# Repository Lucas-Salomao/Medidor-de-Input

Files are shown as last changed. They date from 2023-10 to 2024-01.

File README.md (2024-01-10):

# Dispositivo portátil de medição de input

Este dispositivo é capaz de medir o tempo entre 2 pulsos de um sensor e converter esse tempo em uma tensão de 0-5V, dividido em 2 canais, um para segundos inteiros e outro para milisegundos.

## Características

- Tensão de alimentação: 10-30 VDC
- Display LCD de 2 linhas e 16 colunas para exibição
- Memória EEPROM para armazenar configuração e dados de calibração.
- 1 porta de comunicação serial-USB
- Encoder rotativo para parametrização
- Acurácia de ± 1LSB
- 12 bits de resolução

## Diagrama Esquemático



## Pinout Arduino Nano



## Procedimentos para Compilação e Gravação

O projeto foi desenvolvido no Visual Studio Code, utilizando a extensão [PlatformIO](https://platformio.org/).

É necessário ter o [Arduino IDE Legacy](https://www.arduino.cc/en/software) instalado para poder compilar e gravar a aplicação.

Fazer o download deste repositório, descompactar a pasta e abrir a pasta pelo Visual Studio Code. Assim toda a estrutura do projeto será reconhecida.

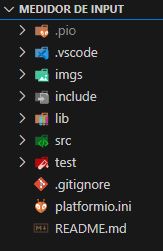
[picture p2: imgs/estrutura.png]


Para compilar o projeto basta utilizar o seguinte atalho no teclado: CTRL+ALT+B. É possível também utilizar o atalho clicando no ícone que se encontra no rodapé do Visual Studio Code.



Para fazer o upload do programa para o dispositivo, com o cabo USB inserido no dispositivo e no computador, utilize o seguinte atalho no teclado: CTRL+ALT+U. É possível também utilizar o atalho clicando no ícone que se encontra no rodapé do Visual Studio Code.



Todas as bibliotecas utilizadas são listadas no arquivo [platfomio.ini](/platformio.ini) e são instaladas assim que a estrutura do projeto é aberto no Visual Studio Code. Para utilizar o Arduino IDE será necessário instalar manualmente cada biblioteca.

## Modo de Funcionamento

Ao energizar o equipamento está pronto para operação, apresentando a seguinte tela:

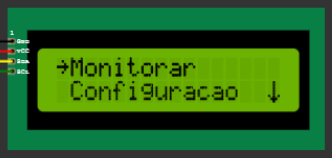
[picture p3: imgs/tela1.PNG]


Nesta tela temos as 2 opções disponíveis, Monitoramento e Configuração.

O encoder rotativo é utilizado para a navegação no menu.

Rotacionando no sentido horário, os valores são incrementados e o menu é deslocado para baixo.

Rotacionando no sentido anti-horário, os valores são decrementados e o menu é deslocado para cima.

O encoder rotativo também apresenta um botão. Quando pressionado o centro do encoder, esse botão é acionado. O Botão apresenta 3 funções:

- Pressionando 1 vez o comando ENTER é enviado.
- Prssionando 2 vezes o comando VOLTAR é enviado e o menu volta um nível acima.
- Pressionando 3 vezes o comando RESET é enviado e o dispositivo é reiniciado.
- Pressionando 1 vez e segurando pelo menos 500ms, o comando APAGAR é enviado e o valor atual selecionado no display é apagado.

No menu Monitoramento podemos encontrar os valores de tempo medidos e os respectivos valores de tensão na saída, calculados.

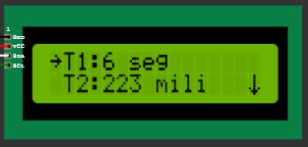
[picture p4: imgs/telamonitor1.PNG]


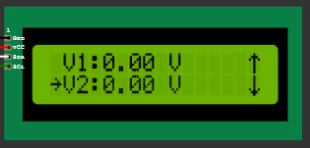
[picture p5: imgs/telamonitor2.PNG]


No menu Configuração podemos configurar os seguintes parâmetros:

- Quantidades de Voltas
- Tempo Máximo de Amostragem
- Precisão da Saída Analógica
- Habilitar Rotina de Teste
- Tempo da Rotina de Teste
- Apagar Memória EEPROM

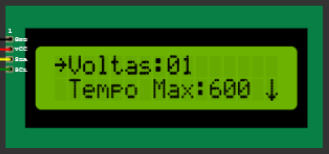
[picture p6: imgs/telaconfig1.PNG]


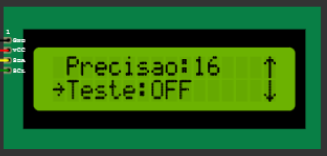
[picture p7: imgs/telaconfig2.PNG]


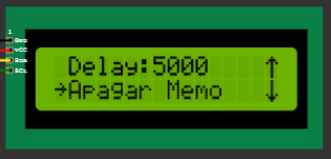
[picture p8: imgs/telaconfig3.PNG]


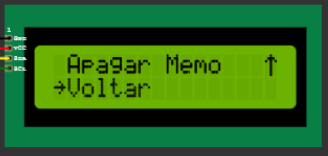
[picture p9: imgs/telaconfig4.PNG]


Para configurar algum valor de parâmetro, basta selecionar o parâmetro desejado e pressionar 1 vez o botão do encoder. O cursor piscará esperando o novo valor. Com o encoder, gire até o valor desejado. Para confirmar o valor, pressione 1 vez novamente o encoder. Caso necessite de mais um algarismo, escolha através do giro do encoder e confirme novamente pressionando 1 vez o encoder. Caso necessite apagar algum algarismo, pressione e segure por pelo menos 500ms o encoder e espere o algarismo ser apagado no display. Caso tenha terminado a configuração, pressione 2 vezes o botão do encoder para voltar ao menu de configuração.

## Licença

[MIT](https://choosealicense.com/licenses/mit/)

## Suporte

Para suporte, mande um e-mail para contato@dksolutions.com.br.

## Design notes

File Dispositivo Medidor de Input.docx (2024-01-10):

DESCRITIVO TÉCNICO

DISPOSITIVO PORTÁTIL DE

MEDIÇÃO DE INPUT

# Dispositivo portátil de medição de input

Este dispositivo é capaz de medir o tempo entre 2 pulsos de um sensor e converter esse tempo em uma tensão de 0-5V, dividido em 2 canais, um para segundos inteiros e outro para milisegundos.

## Características

- Tensão de alimentação: 10-30 VDC
- Display LCD de 2 linhas e 16 colunas para exibição
- Memória EEPROM para armazenar configuração e dados de calibração.
- 1 porta de comunicação serial-USB
- Encoder rotativo para parametrização
- Acurácia de ± 1LSB
- 12 bits de resolução

## Diagrama Esquemático

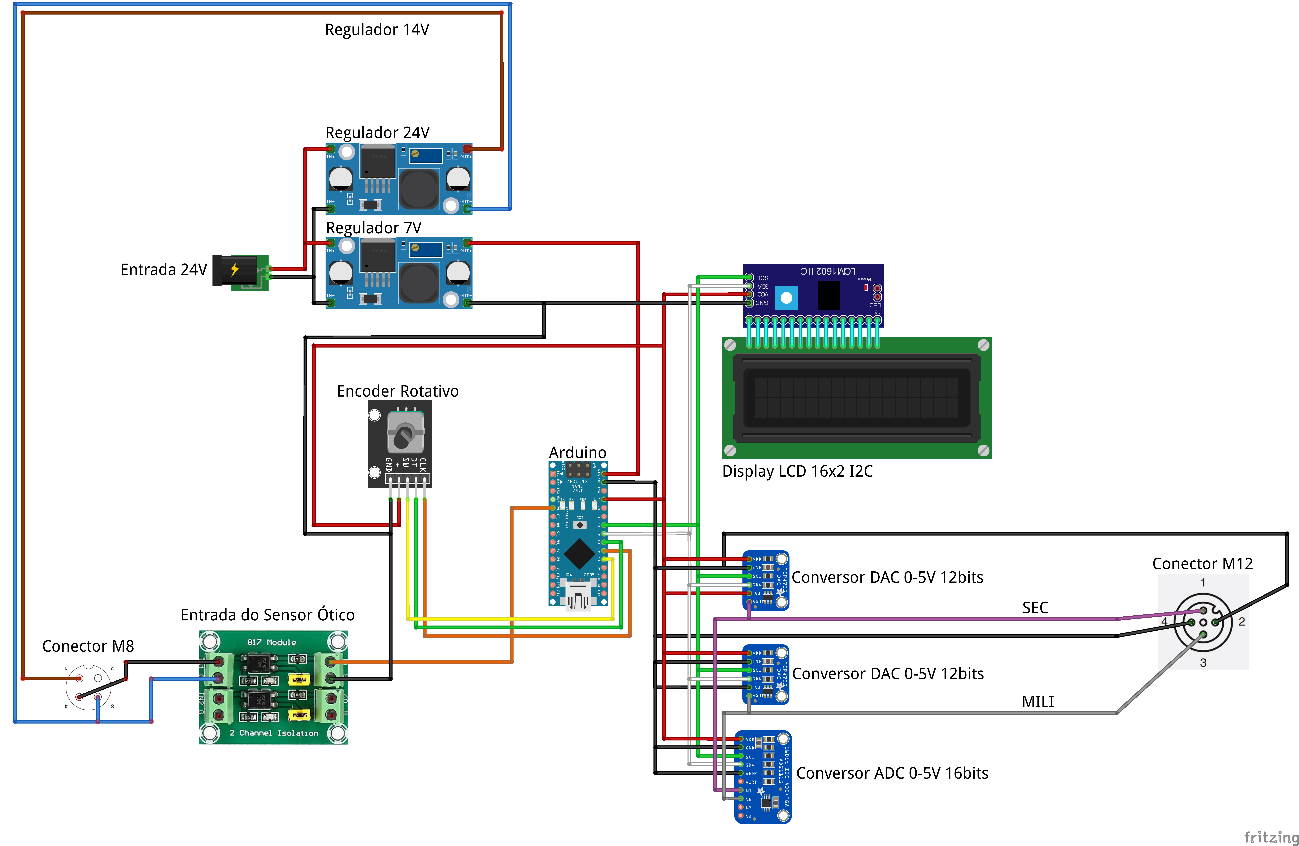
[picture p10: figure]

## Pinout Arduino Nano

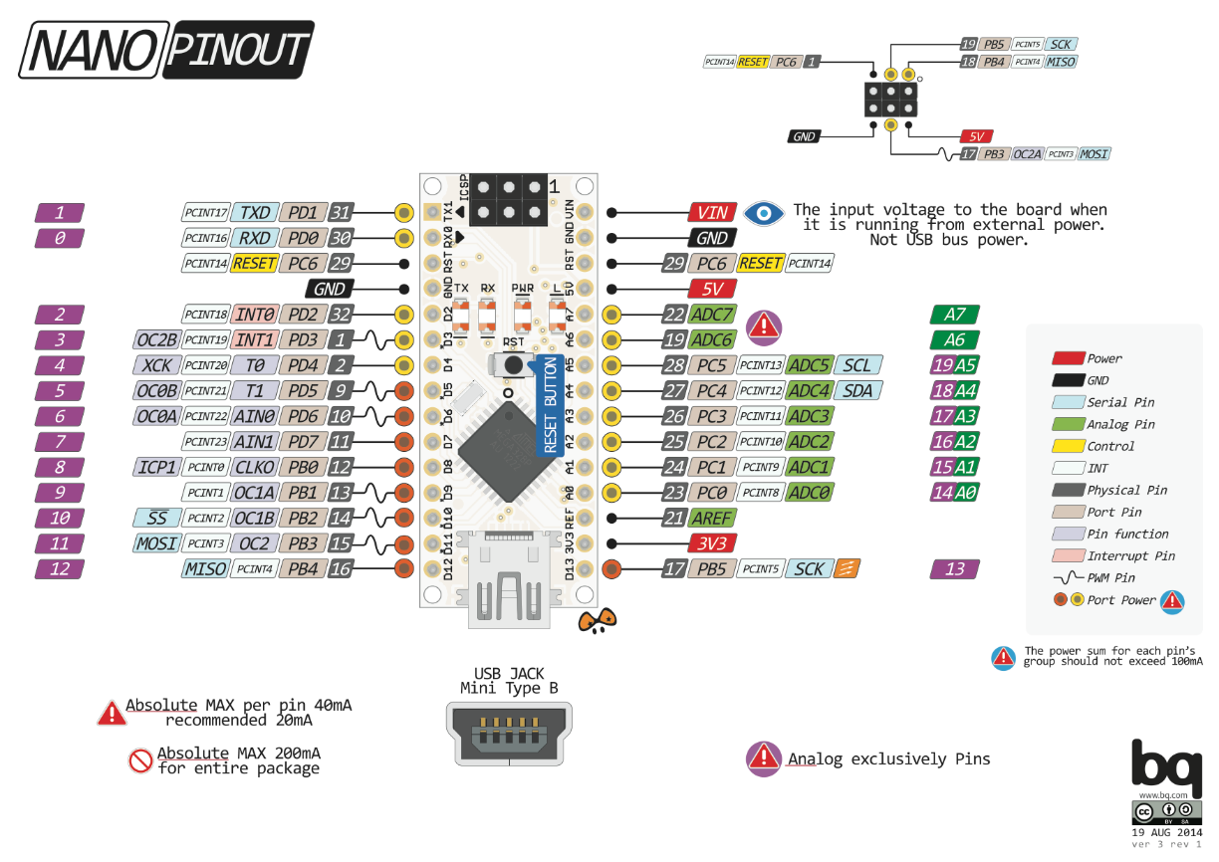
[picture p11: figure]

## Procedimentos para Compilação e Gravação

O projeto foi desenvolvido no Visual Studio Code, utilizando a extensão PlatformIO (https://platformio.org/).

É necessário ter o Arduino IDE Legacy (https://www.arduino.cc/en/software) instalado para poder compilar e gravar a aplicação.

Fazer o download deste repositório, descompactar a pasta e abrir a pasta pelo Visual Studio Code. Assim toda a estrutura do projeto será reconhecida.


Para compilar o projeto basta utilizar o seguinte atalho no teclado: CTRL+ALT+B. É possível também utilizar o atalho clicando no ícone que se encontra no rodapé do Visual Studio Code.

Para fazer o upload do programa para o dispositivo, com o cabo USB inserido no dispositivo e no computador, utilize o seguinte atalho no teclado: CTRL+ALT+U. É possível também utilizar o atalho clicando no ícone que se encontra no rodapé do Visual Studio Code.

Todas as bibliotecas utilizadas são listadas no arquivo platfomio.ini (https://github.com/Lucas-Salomao/Medidor-de-Input/blob/novo-update-display/platformio.ini) e são instaladas assim que a estrutura do projeto é aberto no Visual Studio Code. Para utilizar o Arduino IDE será necessário instalar manualmente cada biblioteca.

## Modo de Funcionamento

Ao energizar o equipamento está pronto para operação, apresentando a seguinte tela:


Nesta tela temos as 2 opções disponíveis, Monitoramento e Configuração.

O encoder rotativo é utilizado para a navegação no menu.

Rotacionando no sentido horário, os valores são incrementados e o menu é deslocado para baixo.

Rotacionando no sentido anti-horário, os valores são decrementados e o menu é deslocado para cima.

O encoder rotativo também apresenta um botão. Quando pressionado o centro do encoder, esse botão é acionado. O Botão apresenta 3 funções:

- Pressionando 1 vez o comando ENTER é enviado.
- Pressionando 2 vezes o comando VOLTAR é enviado e o menu volta um nível acima.
- Pressionando 3 vezes o comando RESET é enviado e o dispositivo é reiniciado.
- Pressionando 1 vez e segurando pelo menos 500ms, o comando APAGAR é enviado e o valor atual selecionado no display é apagado.

No menu Monitoramento podemos encontrar os valores de tempo medidos e os respectivos valores de tensão na saída, calculados.


No menu Configuração podemos configurar os seguintes parâmetros:

- Quantidades de Voltas
- Tempo Máximo de Amostragem
- Precisão da Saída Analógica
- Habilitar Rotina de Teste
- Tempo da Rotina de Teste
- Apagar Memória EEPROM


Para configurar algum valor de parâmetro, basta selecionar o parâmetro desejado e pressionar 1 vez o botão do encoder. O cursor piscará esperando o novo valor. Com o encoder, gire até o valor desejado. Para confirmar o valor, pressione 1 vez novamente o encoder. Caso necessite de mais um algarismo, escolha através do giro do encoder e confirme novamente pressionando 1 vez o encoder. Caso necessite apagar algum algarismo, pressione e segure por pelo menos 500ms o encoder e espere o algarismo ser apagado no display. Caso tenha terminado a configuração, pressione 2 vezes o botão do encoder para voltar ao menu de configuração.

## Licença

MIT (https://choosealicense.com/licenses/mit/)

## Suporte

Para suporte, mande um e-mail para contato@dksolutions.com.br

contato@dksolutions.com.br | 11 2640-3475 / 9.3440-5066 | www.dksolutions.com.br

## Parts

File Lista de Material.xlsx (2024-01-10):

Descrição | Quantidade | Valor | Fornecedor 1 | Fornecedor 2 | Fornecedor 3 | Fornecedor 4 | Fornecedor 5
Arduino Nano | 1 | R$61.65 | https://www.makerhero.com/produto/placa-nano-v3-0-cabo-usb-para-arduino/ |  |  | https://www.autocorerobotica.com.br/arduino-nano-v3-0-compativel-com-cabo-usb | https://www.baudaeletronica.com.br/produto/arduino-nano-r3-compativel-cabo-mini-usb.html
Base com borne Arduino Nano | 1 | R$15.10 | https://www.makerhero.com/produto/nano-shield-para-arduino/ | https://www.eletrogate.com/placa-de-expansao-para-arduino-nano-desmontada |  | https://www.autocorerobotica.com.br/nano-shield-placa-de-expansao-arduino | https://www.baudaeletronica.com.br/produto/shield-de-expansao-com-borne-para-arduino-nano-diy.html
Regulador de Tensão LM2596 | 2 | R$9.40 | https://www.makerhero.com/produto/regulador-de-tensao-lm2596-conversor-dc-dc-step-down/ |  |  | https://www.autocorerobotica.com.br/modulo-regulador-de-tensao-ajustavel-lm2596 | Módulo Regulador de Tensão LM2596 | Baú da Eletrônica - Baú da Eletrônica - Componentes Eletrônicos (baudaeletronica.com.br) (https://www.baudaeletronica.com.br/produto/modulo-regulador-de-tensao-lm2596.html)
Encoder KY-040 | 1 | R$9.40 | https://www.makerhero.com/produto/encoder-decoder-ky-040-rotacional/ | https://www.eletrogate.com/encoder-decoder-ky-040-rotacional |  | https://www.autocorerobotica.com.br/modulo-encoder-rotacional-com-knob | Encoder Decoder KY-040 Rotacional | Baú da Eletrônica - Baú da Eletrônica - Componentes Eletrônicos (baudaeletronica.com.br) (https://www.baudaeletronica.com.br/produto/encoder-decoder-ky-040-rotacional.html)
Display LCD 16x2 com I2C | 1 | R$36.00 | https://www.makerhero.com/produto/display-lcd-16x2-i2c-backlight-azul/ | https://www.eletrogate.com/display-lcd-16x2-i2c-backlight-azul |  | Display Lcd 16x2 com Adaptador I2C Backlight Azul - AutoCore Robótica (autocorerobotica.com.br) (https://www.autocorerobotica.com.br/display-lcd-16x2-com-adaptador-i2c-backlight-azul) | https://www.baudaeletronica.com.br/produto/display-lcd-16x2-azul-com-modulo-adaptador-i2c.html
Optoacoplador | 1 | R$16.90 |  | Módulo Optoacoplador 2 Canais - PC817 - Eletrogate | Arduino, Robótica, IoT, Apostilas e Kits (https://www.eletrogate.com/modulo-optoacoplador-2-canais-pc817) |  |  | Módulo Optoacoplador PC817 com 2 Canais | Baú da Eletrônica - Baú da Eletrônica - Componentes Eletrônicos (baudaeletronica.com.br) (https://www.baudaeletronica.com.br/produto/modulo-optoacoplador-pc817-com-2-canais.html)
Conector P4 | 1 | R$2.38 |  | Conector Jack P4 Femea (J4 2,1mm) DC-022 - Eletrogate | Arduino, Robótica, IoT, Apostilas e Kits (https://www.eletrogate.com/conector-jack-p4-femea-j4-21mm-dc-022)
Conversor Digital Analógico MCP4725 12bits | 2 | R$28.40 | Conversor Digital Analógico DAC MCP4725 I2C - MakerHero (https://www.makerhero.com/produto/conversor-digital-analogico-dac-mcp4725-i2c/) | Conversor Digital Analógico MCP4725 - Eletrogate | Arduino, Robótica, IoT, Apostilas e Kits (https://www.eletrogate.com/conversor-digital-analogico-mcp4725) |  | Módulo MCP4725 Conversor Digital Analógico - AutoCore Robótica (autocorerobotica.com.br) (https://www.autocorerobotica.com.br/modulo-mcp4725-conversor-digital-analogico) | Conversor Digital Analógico DAC - MCP4725 I2C | Baú da Eletrônica - Baú da Eletrônica - Componentes Eletrônicos (baudaeletronica.com.br) (https://www.baudaeletronica.com.br/produto/conversor-digital-analogico-dac-mcp4725-i2c.html)
Conversor Analógico Digital ADS1115 | 1 |  | https://www.makerhero.com/produto/conversor-analogico-digital-4-canais-ads1115/ | https://www.eletrogate.com/modulo-conversor-analogico-digital-adc-ads1115 |  | https://www.autocorerobotica.com.br/modulo-adc-ads1115 | https://www.baudaeletronica.com.br/produto/conversor-analogicodigital-i2c-16-bits-ads1115.html
Caixa Patola PB-119/2 | 1 | R$43.90 |  |  |  |  | Caixa Plástica Patola PB-119/2 | Baú da Eletrônica - Baú da Eletrônica - Componentes Eletrônicos (baudaeletronica.com.br) (https://www.baudaeletronica.com.br/produto/caixa-plastica-patola-pb-1192.html)
Kit de Espaçadores | 1 | R$82.98 |  |  |  |  | https://www.baudaeletronica.com.br/produto/kit-espacadores-m3.html
Cabo Manga 8 vias sem blindagem | 2 | R$8.55 |  |  |  |  | https://www.baudaeletronica.com.br/produto/cabo-manga-8x26-8-vias-26-awg-014mm2-sem-blindagem.html
Conector M12 Fêmea Painel | 1 | R$43.00 |  |  | https://www.recontrolstore.com.br/cabos-e-acessorios/conector-m12-painel-4-pinos-femea-
Conector M12 Macho Reto | 1 | R$34.00 |  |  | https://www.recontrolstore.com.br/conectores-montaveis-m12-m8/conector-m12-pg7-reto-4pin-macho
Conector M8 Fêmea Painel | 1 | R$45.00 |  |  | CONECTOR M8 PAINEL 4 PINOS FEMEA - R.E. Control Store (recontrolstore.com.br) (https://www.recontrolstore.com.br/conectores-montaveis/conectores-m8/conector-m8-painel-4-pinos-femea)
TOTAL |  | R$436.66

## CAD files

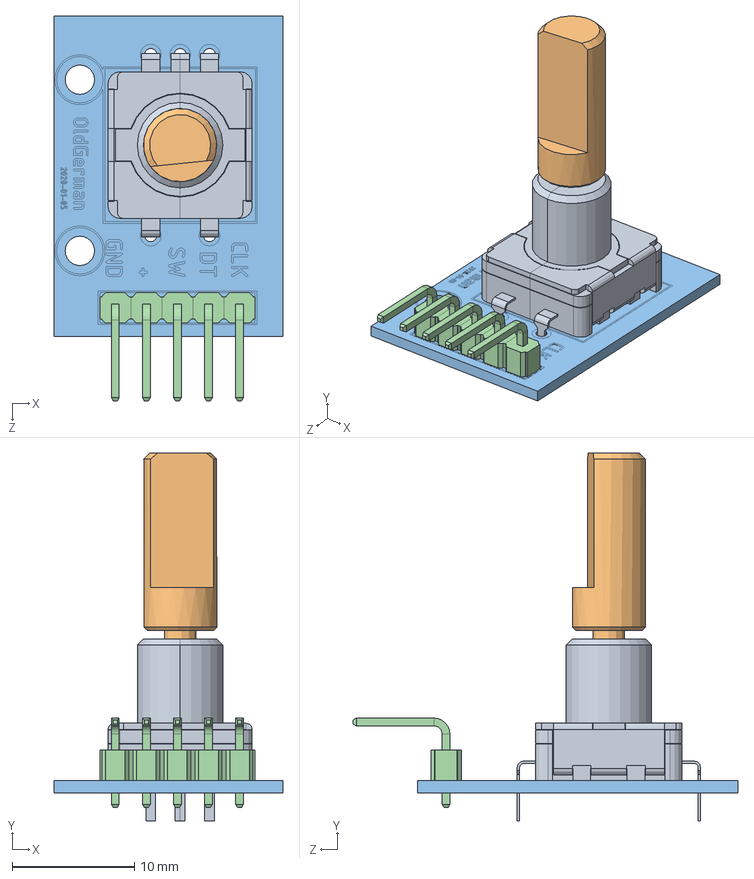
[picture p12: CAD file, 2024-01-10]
3D/KY-040 Rotary Encoder.SLDASM
18.7 x 30.1 x 31.5 mm
Rotary Encoder
D-handle
pcb
2.54 5PIN 90

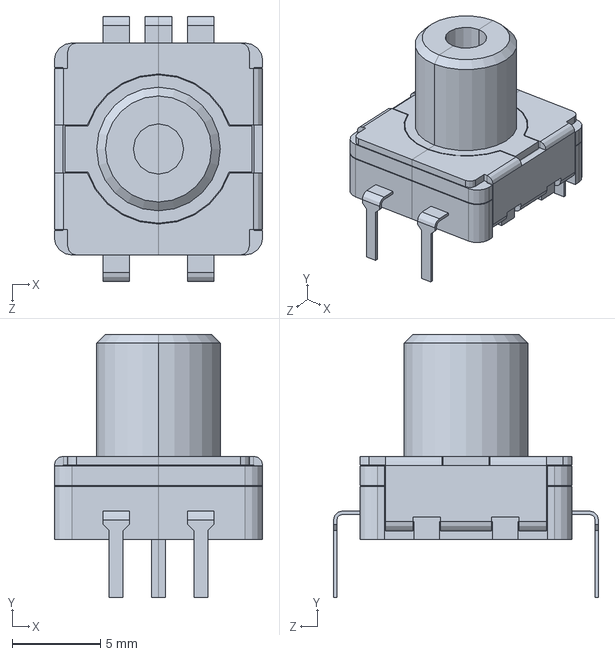
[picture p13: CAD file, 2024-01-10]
3D/Rotary Encoder.SLDPRT
11.8 x 14.9 x 15.0 mm

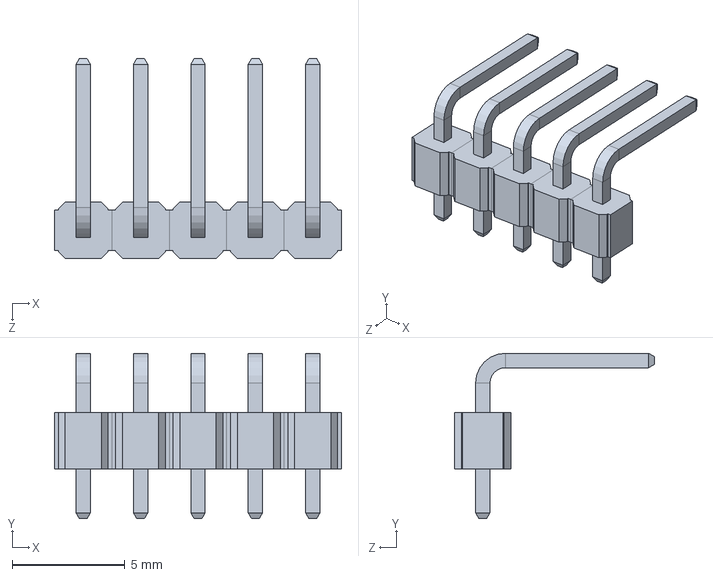
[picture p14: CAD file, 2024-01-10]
3D/2.54 5PIN 90.SLDPRT
12.7 x 7.32 x 8.85 mm

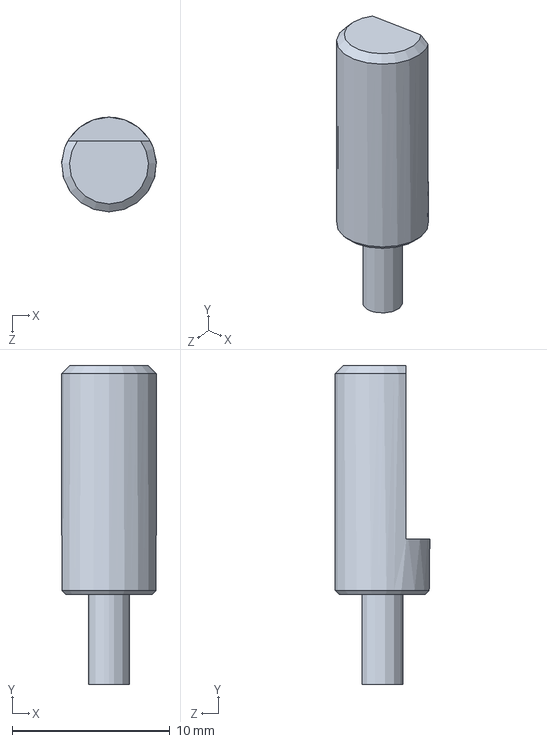
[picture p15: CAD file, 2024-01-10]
3D/D-handle.SLDPRT
6.00 x 20.2 x 6.00 mm

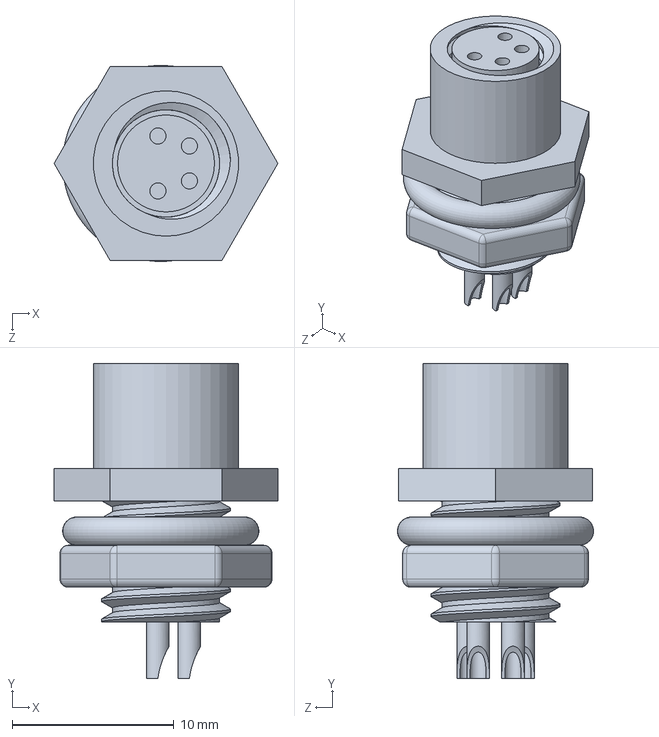
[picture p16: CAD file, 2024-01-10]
3D/connectorFemaleFlange.SLDPRT
13.9 x 19.5 x 12.1 mm

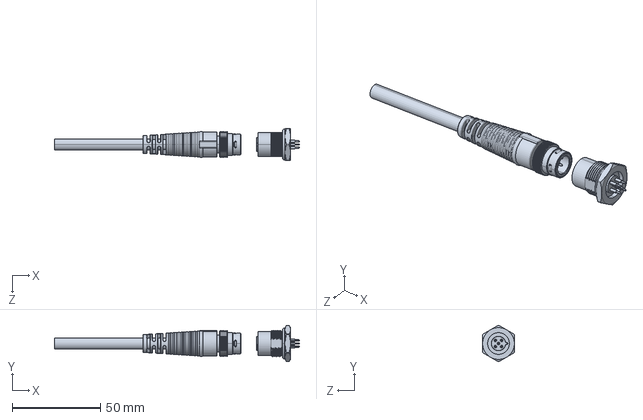
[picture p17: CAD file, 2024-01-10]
3D/Circle M12 push pull 5pin connector detal model.SLDPRT
138.6 x 20.6 x 18.0 mm

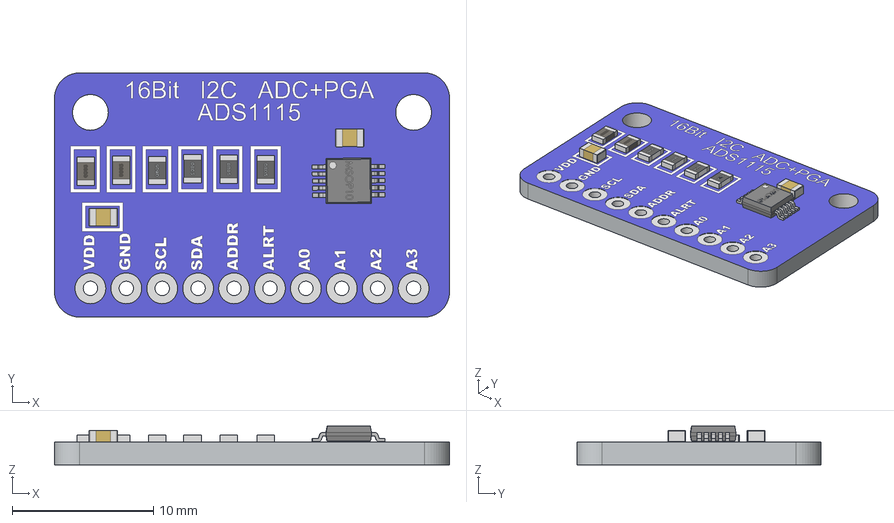
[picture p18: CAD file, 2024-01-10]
3D/16Bit I2C ADC+PGA - ADS1115.stp
27.9 x 17.3 x 2.74 mm
ADS1115
0805 Capacitor x 2
0805 Inductor x 2
0805 Resistor x 4
MSOP10

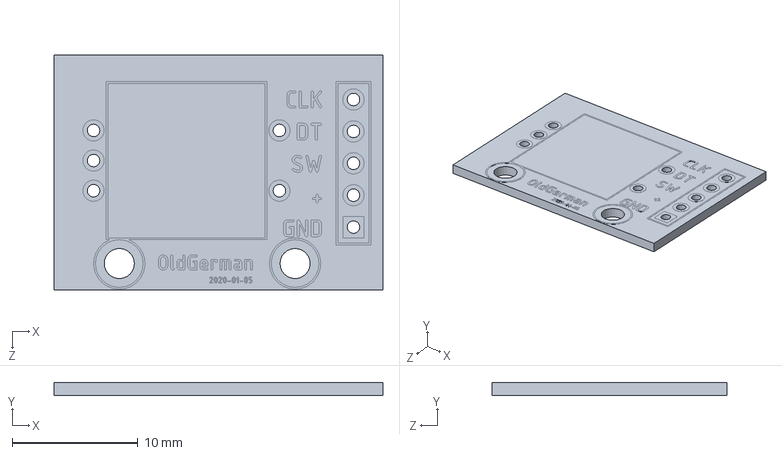
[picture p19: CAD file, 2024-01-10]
3D/pcb.SLDPRT
26.2 x 1.02 x 18.7 mm

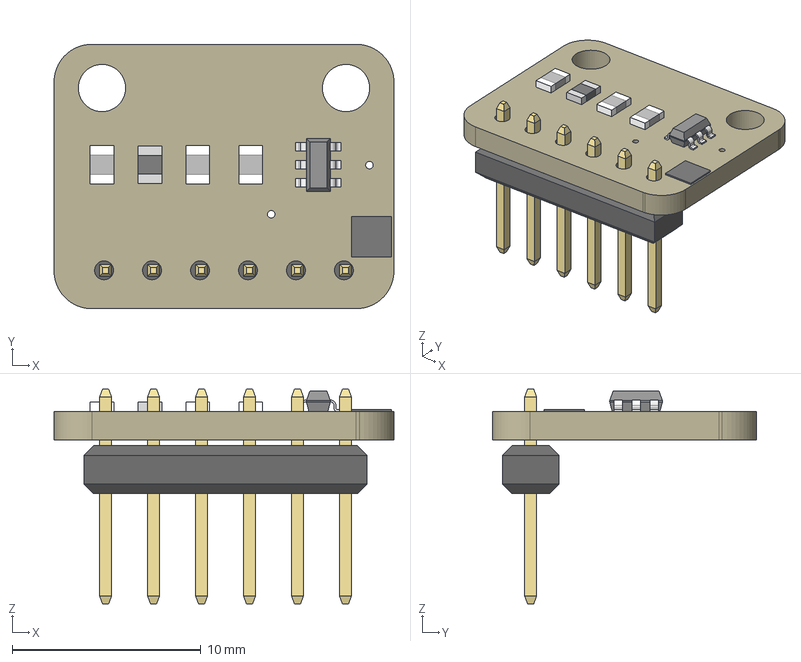
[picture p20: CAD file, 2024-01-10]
3D/Adafruit MCP4725.step
18.0 x 14.0 x 11.4 mm
Board
Ferrite
Contact x 2
ADAFRUIT_2.5MM
SOT23-6
FIDUCIAL_1MM
FIDUCIAL_1MM (1)
MOUNTINGHOLE_2.5_PLATED
MOUNTINGHOLE_2.5_PLATED (1)
1X06_ROUND_70

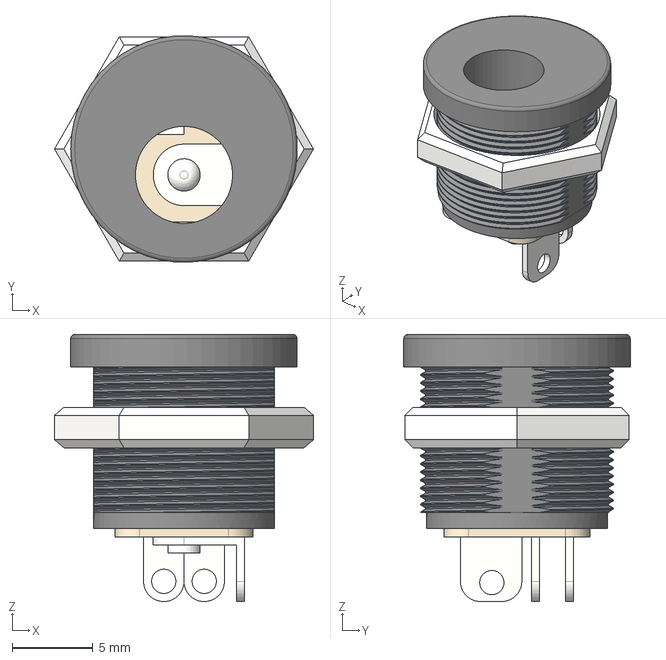
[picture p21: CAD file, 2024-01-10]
3D/Jack Plug P4.step
16.0 x 14.0 x 16.5 mm

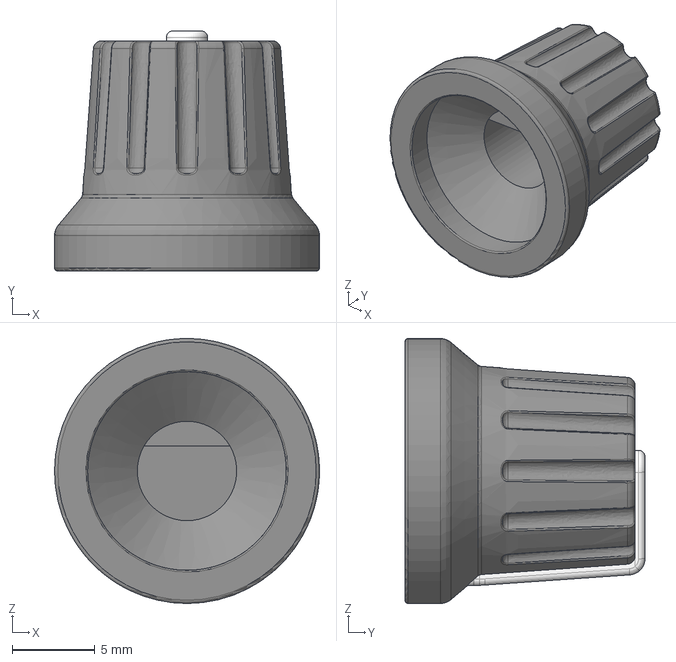
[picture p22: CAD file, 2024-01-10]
3D/Rotary Knob.step
16.0 x 14.5 x 16.0 mm

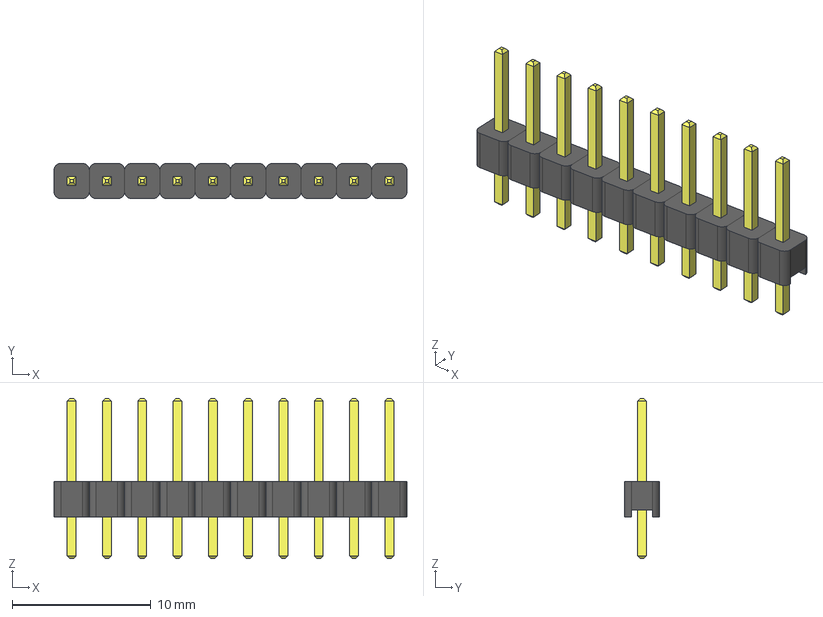
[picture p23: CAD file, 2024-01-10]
3D/BPSC-10.stp
25.4 x 2.54 x 11.5 mm
Pino
Base
Pino001
Base001
Pino002
Base002
Pino003
Base003
Pino004
Base004
Pino005
Base005
Pino006
Base006
Pino007
Base007
Pino008
Base008
Pino009
Base009

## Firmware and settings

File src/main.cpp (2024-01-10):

/*
Copyright (c) Lucas Salomao <lucastadeusalomao@gmail.com>

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
PINAGEM CONECTOR SENSOR M12
Marrom 2 SINAL 1 MILISEGUNDOS
Amarelo 1 GND 1
Vermelho 4 SINAL 2 SEGUNDOS
Laranja 3 GND 2

*/

#include <Arduino.h>
#include <RotaryEncoder.h>
#include <ItemInput.h>
#include <ItemSubMenu.h>
#include <ItemCommand.h>
#include <ItemToggle.h>
#include <LcdMenu.h>
#include "Button2.h"
#include "pwm16.h"
#include <Adafruit_MCP4725.h>
#include <ArduinoJson.h>
#include <StreamUtils.h>
#include <EEPROM.h>
#include <math.h>
#include <Adafruit_ADS1X15.h>

#define PIN_IN1 A2
#define PIN_IN2 A3
#define LCD_ROWS 2
#define LCD_COLS 16
#define LCD_ADDR 0x27
#define CHARSET_SIZE 11
#define CONFIG_ADDR 0x00
#define BUTTON_PIN A1
#define EEPROM_SIZE 1024
#define PWMSEC 9
#define PWMMILI 10

RotaryEncoder *encoder = nullptr;
LcdMenu menu(LCD_ROWS, LCD_COLS); // Construct the LcdMenu
Button2 button;
Adafruit_MCP4725 DACSec;
Adafruit_MCP4725 DACMili;
//Adafruit_ADS1X15 ADS1X15;
Adafruit_ADS1115 ADS1X15;

extern MenuItem *settingsMenu[];
extern MenuItem *monitorMenu[];

int valor = 0;
int newPos = 0;
int pos = 0;
struct Config
{
  char voltas[3];
  char tempoMax[4];
  char pwm[3];
  char delay[6];
  char precisao[4];
};
Config config;
char charset[] = {'0', '1', '2', '3', '4', '5', '6', '7', '8', '9', '.'};
uint8_t charsetPosition=0;
volatile unsigned long int current_time = 0;
volatile unsigned long int last_time = 0;
volatile unsigned long int elapsed_time = 0;
volatile unsigned long int tempo_total = 0;
volatile uint8_t volta_atual = 0;
volatile uint8_t volta_configurada = 1;
volatile uint16_t tempo_maximo = 600;
volatile uint16_t tempo_segundos = 0;
volatile uint16_t tempo_milisegundos = 0;
volatile float voltageSec = 0.0;
volatile float voltageMili = 0.0;
volatile uint16_t pwmBits = 12;
char str_segundos[16];
char str_milisegundos[16];
char str_tensao_segundos[16];
char str_tensao_milisegundos[16];
volatile uint16_t teste = 0;
volatile unsigned long tempo_atual_dac;
volatile unsigned long tempo_anterior_dac;
volatile unsigned long tempo_atraso_teste = 1000;
volatile uint16_t dac_voltage = 0;
volatile unsigned long tempo_atual_pwm;
volatile unsigned long tempo_anterior_pwm;
volatile uint16_t pwm_bits = 0;
volatile uint8_t atualiza_tensao = 0;
volatile uint16_t adc_sec, adc_mili = 0;
volatile float tensao_ads_sec, tensao_ads_mili = 0.0;
volatile int16_t corretor = 0;
volatile uint16_t precisao_bits_dac = 16;
volatile int16_t erroDAC=0;
volatile int16_t corretor_mili=0;
volatile uint8_t atualiza_tensao_mili=0;

void (*funcReset)() = 0;
void menu_back(void);
void read_encoder(void);
void handler(Button2 &btn);
void time_to_pwm();
void time_to_voltage();
void inputCallbackVoltas(char *value);
void inputCallbackTempoMax(char *value);
void inputCallbackPWM(char *value);
void inputCallbackDelay(char *value);
void inputCallbackPrecisao(char *value);
void save_configuration(void);
void load_configuration(void);
void EEPROM_Clear(void);
void update_display(void);
void test_output(void);
void rotina_teste(uint16_t isOn);
long mapeamento(long x, long in_min, long in_max, long out_min, long out_max);
void read_ADS(void);
void corrige_DACSec(void);
void atualiza_tempo(void);
void corrige_DACMili(void);

MAIN_MENU(
    ITEM_SUBMENU("Monitorar", monitorMenu),
    ITEM_SUBMENU("Configuracao", settingsMenu));

SUB_MENU(settingsMenu, mainMenu,
         ITEM_INPUT("Voltas", config.voltas, inputCallbackVoltas),
         ITEM_INPUT("Tempo Max", config.tempoMax, inputCallbackTempoMax),
         ITEM_INPUT("Precisao",config.precisao,inputCallbackPrecisao),
         //ITEM_INPUT("PWM-Resol", config.pwm, inputCallbackPWM),
         ITEM_TOGGLE("Teste", "ON", "OFF", rotina_teste),
         ITEM_INPUT("Delay", config.delay, inputCallbackDelay),
         ITEM_COMMAND("Apagar Memo", EEPROM_Clear),
         ITEM_COMMAND("Voltar", menu_back));
SUB_MENU(monitorMenu, mainMenu,
         ITEM_BASIC(str_segundos),
         ITEM_BASIC(str_milisegundos),
         ITEM_BASIC(str_tensao_segundos),
         ITEM_BASIC(str_tensao_milisegundos),
         ITEM_COMMAND("Voltar", menu_back));

void read_encoder(void)
{
  int newPos = encoder->getPosition();
  // if (pos != newPos)
  // {
  //   Serial.print("pos:");
  //   Serial.print(newPos);
  //   Serial.print(" dir:");
  //   Serial.println((int)(encoder->getDirection()));
  // }
  if (newPos > pos)
  {
    if (menu.isInEditMode()) // Update the position only in edit mode
      charsetPosition = (charsetPosition + 1) % CHARSET_SIZE;
    menu.drawChar(charset[charsetPosition]); // Works only in edit mode
    menu.down();
    pos = newPos;
  }
  if (newPos < pos)
  {
    if (menu.isInEditMode()) // Update the position only in edit mode
      charsetPosition = constrain(charsetPosition - 1, 0, CHARSET_SIZE);
    menu.drawChar(charset[charsetPosition]); // Works only in edit mode
    menu.up();
    pos = newPos;
  }
}

void handler(Button2 &btn)
{
  switch (btn.getType())
  {
  case single_click:
    menu.type(charset[charsetPosition]); // Works only in edit mode
    menu.enter();
    break;
  case double_click:
    menu.back();
    menu.setCursorPosition(0);
    break;
  case triple_click:
    funcReset();
    break;
  case long_click:
    menu.backspace();
    break;
  case empty:
    break;
  }
}

void time_to_pwm()
{
  uint16_t pwmSec, pwmMili = 0;

  uint16_t resolution = (uint16_t)pow(2, pwmBits);
  uint16_t fundo_escala = resolution - 1;

  pwmSec = (uint16_t)mapeamento(tempo_segundos, 0, tempo_maximo, 0, fundo_escala);
  pwmMili = (uint16_t)mapeamento(tempo_milisegundos, 0, 999, 0, fundo_escala);

  analogWrite16(PWMSEC, pwmSec);
  analogWrite16(PWMMILI, pwmMili);

  voltageSec = (10.0 / resolution) * pwmSec;
  voltageMili = (10.0 / resolution) * pwmMili;
}

void time_to_voltage()
{
  uint16_t t = mapeamento(tempo_segundos, 0, tempo_maximo, 0, 4095);
  DACSec.setVoltage(t + erroDAC + corretor, false);
  voltageSec = t * (5.0 / 4096);
  t = mapeamento(tempo_milisegundos, 0, 999, 0, 4095);
  DACMili.setVoltage(t + erroDAC + corretor_mili, false);
  voltageMili = t * (5.0 / 4096);

  //Serial.print(F("DAC-Tensao segundos:"));
  //Serial.println(voltageSec,6);
  //Serial.print(F("DAC-Tensao milisegundos:"));
  //Serial.println(voltageMili,6);
}

void test_output(void)
{
  uint16_t resolution = (uint16_t)pow(2, pwmBits);

  analogWrite16(PWMSEC, (resolution / 8) * 0);
  analogWrite16(PWMMILI, (resolution / 8) * 0);
  DACMili.setVoltage(0, false);
  DACSec.setVoltage(0, false);
  read_ADS();
  delay(tempo_atraso_teste);

  analogWrite16(PWMSEC, ((resolution / 8) * 1) - 1);
  analogWrite16(PWMMILI, ((resolution / 8) * 1) - 1);
  DACMili.setVoltage(511, false);
  DACSec.setVoltage(511, false);
  read_ADS();
  delay(tempo_atraso_teste);

  analogWrite16(PWMSEC, ((resolution / 8) * 2) - 1);
  analogWrite16(PWMMILI, ((resolution / 8) * 2) - 1);
  DACMili.setVoltage(1023, false);
  DACSec.setVoltage(1023, false);
  read_ADS();
  delay(tempo_atraso_teste);

  analogWrite16(PWMSEC, ((resolution / 8) * 3) - 1);
  analogWrite16(PWMMILI, ((resolution / 8) * 3) - 1);
  DACMili.setVoltage(1535, false);
  DACSec.setVoltage(1535, false);
  read_ADS();
  delay(tempo_atraso_teste);

  analogWrite16(PWMSEC, ((resolution / 8) * 4) - 1);
  analogWrite16(PWMMILI, ((resolution / 8) * 4) - 1);
  DACMili.setVoltage(2047, false);
  DACSec.setVoltage(2047, false);
  read_ADS();
  delay(tempo_atraso_teste);

  analogWrite16(PWMSEC, ((resolution / 8) * 5) - 1);
  analogWrite16(PWMMILI, ((resolution / 8) * 5) - 1);
  DACMili.setVoltage(2559, false);
  DACSec.setVoltage(2559, false);
  read_ADS();
  delay(tempo_atraso_teste);

  analogWrite16(PWMSEC, ((resolution / 8) * 6) - 1);
  analogWrite16(PWMMILI, ((resolution / 8) * 6) - 1);
  DACMili.setVoltage(3071, false);
  DACSec.setVoltage(3071, false);
  read_ADS();
  delay(tempo_atraso_teste);

  analogWrite16(PWMSEC, ((resolution / 8) * 7) - 1);
  analogWrite16(PWMMILI, ((resolution / 8) * 7) - 1);
  DACMili.setVoltage(3583, false);
  DACSec.setVoltage(3583, false);
  read_ADS();
  delay(tempo_atraso_teste);

  analogWrite16(PWMSEC, ((resolution / 8) * 8));
  analogWrite16(PWMMILI, ((resolution / 8) * 8));
  DACMili.setVoltage(4095, false);
  DACSec.setVoltage(4095, false);
  read_ADS();
  delay(tempo_atraso_teste);
}

void inputCallbackVoltas(char *value)
{
  strcpy(config.voltas, value);
  save_configuration();
  volta_configurada = atoi(value);
}

void inputCallbackTempoMax(char *value)
{
  strcpy(config.tempoMax, value);
  save_configuration();
  tempo_maximo = atoi(value);
}

void inputCallbackPWM(char *value)
{
  strcpy(config.pwm, value);
  save_configuration();
  pwmBits = atoi(value);
  setupPWM16(pwmBits);
  pwm_bits = 0;
}

void inputCallbackDelay(char *value)
{
  strcpy(config.delay, value);
  save_configuration();
  tempo_atraso_teste = atoi(value);
}

void inputCallbackPrecisao(char *value)
{
  strcpy(config.precisao,value);
  save_configuration();
  precisao_bits_dac=atoi(value);
}

void menu_back(void)
{
  menu.back();
}

void save_configuration(void)
{
  // Allocate a temporary JsonDocument
  // Don't forget to change the capacity to match your requirements.
  // Use https://arduinojson.org/assistant to compute the capacity.
  StaticJsonDocument<128> doc;

  // Set the values in the document
  doc["voltas"] = config.voltas;
  doc["tempoMax"] = config.tempoMax;
  doc["pwm"] = config.pwm;
  doc["delay"] = config.delay;
  doc["precisao"] = config.precisao;

  EepromStream eepromStream(CONFIG_ADDR, sizeof(doc));
  serializeJson(doc, eepromStream);
  //Serial.println(F("Configuracoes salvas com sucesso"));
}

void load_configuration(void)
{
  // Allocate a temporary JsonDocument
  // Don't forget to change the capacity to match your requirements.
  // Use https://arduinojson.org/v6/assistant to compute the capacity.
  StaticJsonDocument<128> doc;

  EepromStream eepromStream(CONFIG_ADDR, sizeof(doc));
  DeserializationError error = deserializeJson(doc, eepromStream);
  if (error)
  {
    //Serial.print(F("Falha ao ler configuracao da EEPROM, usando configuracoes padrao e recriando o arquivo de configuracao\n\rError:"));
    //Serial.println(error.f_str());
    strlcpy(config.voltas, "01", sizeof("01"));
    strlcpy(config.tempoMax, "600", sizeof("600"));
    strlcpy(config.pwm, "11", sizeof("11"));
    strlcpy(config.delay, "5000", sizeof("5000"));
    strlcpy(config.precisao, "16",sizeof("16"));
    save_configuration();
    load_configuration();
  }
  else
  {
    //Serial.println(F("Configuracao lida com sucesso da EEPROM"));
    strlcpy(config.voltas, doc["voltas"], sizeof(config.voltas));
    strlcpy(config.tempoMax, doc["tempoMax"], sizeof(config.tempoMax));
    strlcpy(config.pwm, doc["pwm"], sizeof(config.pwm));
    strlcpy(config.delay, doc["delay"], sizeof(config.delay));
    strlcpy(config.precisao,doc["precisao"],sizeof(config.precisao));
    volta_configurada = uint8_t(doc["voltas"]);
    pwmBits = uint16_t(doc["pwm"]);
    tempo_maximo = uint16_t(doc["tempoMax"]);
    tempo_atraso_teste = (unsigned long)(doc["delay"]);
    precisao_bits_dac = uint16_t(doc["precisao"]);
    // Serial.print(F("Voltas: "));
    // Serial.println(volta_configurada);
    // Serial.print(F("Resolucao PWM: "));
    // Serial.println(pwmBits);
    // Serial.print(F("Tempo maximo: "));
    // Serial.println(tempo_maximo);
    // Serial.print(F("Tempo delay teste: "));
    // Serial.println(tempo_atraso_teste);
    // Serial.print(F("Precisao: "));
    // Serial.println(precisao_bits_dac);
  }
}

void EEPROM_Clear(void)
{
  //Serial.println(F("Apagando memoria EEPROM"));
  for (unsigned int i = 0; i < EEPROM.length(); i++)
  {
    EEPROM.write(i, 0);
  }
  //Serial.println(F("Memoria EEPROM apagada com sucesso"));
  delay(100);
  funcReset();
}

long mapeamento(long x, long in_min, long in_max, long out_min, long out_max)
{
  float result = (x - in_min) * (out_max - out_min) / (in_max - in_min) + out_min;
  return round(result); // arredonda para o número inteiro mais próximo
}

void update_display(void)
{
  char tempBuffer[16];
  char tempMsg[16];
  int tempNumber=0;
  float tempFloat=0;

  tempNumber=tempo_segundos;
  //itoa(tempNumber,tempBuffer,10);
  //strcpy(str_segundos, tempBuffer);
  sprintf(tempMsg,"T1:%d seg",tempNumber);
  strcpy(str_segundos,tempMsg);

  tempNumber=tempo_milisegundos;
  //itoa(tempNumber,tempBuffer,10);
  //strcpy(str_milisegundos, tempBuffer);
  sprintf(tempMsg,"T2:%d mili",tempNumber);
  strcpy(str_milisegundos,tempMsg);

  tempFloat=voltageSec;
  dtostrf(tempFloat, 4, 2, tempBuffer);
  //strcpy(str_tensao_segundos, tempBuffer);
  sprintf(tempMsg,"V1:%s V",tempBuffer);
  strcpy(str_tensao_segundos,tempMsg);

  tempFloat=voltageMili;
  dtostrf(tempFloat, 4, 2, tempBuffer);
  //strcpy(str_tensao_milisegundos, tempBuffer);
  sprintf(tempMsg,"V2:%s V",tempBuffer);
  strcpy(str_tensao_milisegundos,tempMsg);
}

void rotina_teste(uint16_t isOn)
{
  teste = isOn;
  if (isOn == 0)
  {
    pwm_bits = 0;
    dac_voltage = 0;
  }
}

void read_ADS()
{
  adc_sec = ADS1X15.readADC_SingleEnded(0);
  adc_mili = ADS1X15.readADC_SingleEnded(1);
  tensao_ads_sec = ADS1X15.computeVolts(adc_sec);
  tensao_ads_mili = ADS1X15.computeVolts(adc_mili);

  //Serial.print(F("ADC-Tensao segundos:"));
  //Serial.println(tensao_ads_sec,6);
  //Serial.print(F("ADC-Tensao milisegundos:"));
  //Serial.println(tensao_ads_mili,6);
}

void corrige_DACSec(void)
{
  if (((voltageSec - tensao_ads_sec) > 0) & ((voltageSec - tensao_ads_sec) > (precisao_bits_dac * (6.144 / 65536))))
  {
    corretor++;
    atualiza_tensao = 1;
    return;
  }
  if (((voltageSec - tensao_ads_sec) > 0) & ((voltageSec - tensao_ads_sec) <= (precisao_bits_dac * (6.144 / 65536))))
  {
    atualiza_tensao = 0;
    //Serial.print(F("Corretor:"));
    //Serial.println(corretor);
    //Serial.println();
    return;
  }
  if (((voltageSec - tensao_ads_sec) < 0) & ((voltageSec - tensao_ads_sec) < (-1 * (precisao_bits_dac * (6.144 / 65536)))))
  {
    corretor--;
    atualiza_tensao = 1;
    return;
  }
  if (((voltageSec - tensao_ads_sec) < 0) & ((voltageSec - tensao_ads_sec) > (-1 * (precisao_bits_dac * (6.144 / 65536)))))
  {
    atualiza_tensao = 0;
    //Serial.print(F("Corretor:"));
    //Serial.println(corretor);
    //Serial.println();
    return;
  }
}

void corrige_DACMili(void)
{
  if (((voltageMili - tensao_ads_mili) > 0) & ((voltageMili - tensao_ads_mili) > (precisao_bits_dac * (6.144 / 65536))))
  {
    corretor_mili++;
    atualiza_tensao_mili = 1;
    return;
  }
  if (((voltageMili - tensao_ads_mili) > 0) & ((voltageMili - tensao_ads_mili) <= (precisao_bits_dac * (6.144 / 65536))))
  {
    atualiza_tensao_mili = 0;
    //Serial.print(F("Corretor:"));
    //Serial.println(corretor_mili);
    //Serial.println();
    return;
  }
  if (((voltageMili - tensao_ads_mili) < 0) & ((voltageMili - tensao_ads_mili) < (-1 * (precisao_bits_dac * (6.144 / 65536)))))
  {
    corretor_mili--;
    atualiza_tensao_mili = 1;
    return;
  }
  if (((voltageMili - tensao_ads_mili) < 0) & ((voltageMili - tensao_ads_mili) > (-1 * (precisao_bits_dac * (6.144 / 65536)))))
  {
    atualiza_tensao_mili = 0;
    //Serial.print(F("Corretor:"));
    //Serial.println(corretor_mili);
    //Serial.println();
    return;
  }
}

void checkPosition(void)
{
  encoder->tick(); // just call tick() to check the state.
}

void count_time(void)
{
  if(current_time!=last_time)
  {
    //char msg_time[60];
    if (last_time == 0)
    {
      last_time = current_time;
    }
    // Calcula o tempo decorrido desde a última interrupção
    elapsed_time += current_time - last_time;
    // Atualiza o tempo da interrupção anterior
    last_time = current_time;
    volta_atual++;
    // Se a quantidade de interrupções for atingida, imprime o tempo acumulado na serial
    if (volta_atual > volta_configurada)
    {
      tempo_segundos = elapsed_time / 1000;
      tempo_milisegundos = elapsed_time % 1000;
      //sprintf(msg_time, "Tempo total decorrido: %lu ms", elapsed_time);
      //Serial.println(msg_time);
      elapsed_time = 0;
      volta_atual = 1;
      atualiza_tensao=1;
      atualiza_tensao_mili=1;
      update_display();
    }
  }
  
}

void atualiza_tempo(void)
{
  current_time = millis();
  count_time();
}

ISR(PCINT1_vect)
{
checkPosition();
}

void setup()
{
  Serial.begin(1000000);
  //Serial.println(F("*********************************************************"));
  //Serial.println(F("Iniciando Medidor de Input Rinnai V1.0"));
  //Serial.println(F("Desenvolvido por DK Solutions"));
  //Serial.println(F("Engenheiro Responsavel:Lucas Salomao"));
  //Serial.println(F("Contato:lucastadeusalomao@gmail.com"));
  //Serial.println(F("*********************************************************"));

  //Serial.println(F("Configurando encoder rotativo"));
  // setup the rotary encoder functionality

  // use FOUR3 mode when PIN_IN1, PIN_IN2 signals are always HIGH in latch position.
  // encoder = new RotaryEncoder(PIN_IN1, PIN_IN2, RotaryEncoder::LatchMode::FOUR3);

  // use FOUR0 mode when PIN_IN1, PIN_IN2 signals are always LOW in latch position.
  encoder = new RotaryEncoder(PIN_IN1, PIN_IN2, RotaryEncoder::LatchMode::FOUR0);

  // use TWO03 mode when PIN_IN1, PIN_IN2 signals are both LOW or HIGH in latch position.
  // encoder = new RotaryEncoder(PIN_IN1, PIN_IN2, RotaryEncoder::LatchMode::TWO03);

  // register interrupt routine
  // attachInterrupt(digitalPinToInterrupt(PIN_IN1), checkPosition, CHANGE);
  // attachInterrupt(digitalPinToInterrupt(PIN_IN2), checkPosition, CHANGE);
  // pinMode(PIN_IN1,INPUT_PULLUP);
  // pinMode(PIN_IN2,INPUT_PULLUP);
  PCICR |= (1 << PCIE1);                     // This enables Pin Change Interrupt 1 that covers the Analog input pins or Port C.
  PCMSK1 |= (1 << PCINT10) | (1 << PCINT11); // This enables the interrupt for pin 2 and 3 of Port C.

  //Serial.println(F("Configurando interrupcao do sensor"));
  pinMode(2, INPUT_PULLUP);
  attachInterrupt(digitalPinToInterrupt(2), atualiza_tempo, FALLING);

  // lcd->setCursor(5,0);
  // lcd->print("Rinnai");
  // lcd->setCursor(0,1);
  // lcd->print("Medidor de Input");

  //Serial.println(F("Configurando LCD"));
  menu.setupLcdWithMenu(0x27, mainMenu);
  charsetPosition = 0;

  current_time = 0;
  last_time = 0;
  elapsed_time = 0;
  volta_atual=0;

  //Serial.println(F("Configurando botao do encoder"));
  button.begin(BUTTON_PIN);
  button.setClickHandler(handler);
  button.setLongClickHandler(handler);       // this will only be called upon release
  // button.setLongClickDetectedHandler(handler); // this will only be called upon detection
  button.setDoubleClickHandler(handler);
  button.setTripleClickHandler(handler);

  //Serial.println(F("Lendo configuracoes na EEPROM"));
  load_configuration();

  //Serial.println(F("Configurando saida PWM"));
  //setupPWM16(pwmBits);
  //analogWrite16(PWMSEC, 0);
  //analogWrite16(PWMMILI, 0);

  if(!(DACSec.begin(0x60)&DACMili.begin(0x61)))
  {
    //Serial.println(F("Falha ao iniciar DAC"));
    funcReset();
  }
  {
    //Serial.println(F("DAC inicializado"));
    DACSec.setVoltage(0, false);
    DACMili.setVoltage(0, false);
  }

  if (!ADS1X15.begin())
  {
    //Serial.println(F("Falha ao iniciar ADS"));
    funcReset();
  }
  else
  {
    ADS1X15.setGain(GAIN_TWOTHIRDS);
    ADS1X15.setDataRate(RATE_ADS1115_860SPS);
    //Serial.println(F("ADS inicializado"));
    corretor = 0;
  }
}

void loop()
{
  if (teste == 1)
  {
    test_output();
  }
  else
  {
    read_encoder();
    button.loop();
    if ((atualiza_tensao == 1)|(atualiza_tensao_mili==1))
    {
      time_to_voltage();
      read_ADS();
      corrige_DACSec();
      corrige_DACMili();
    }
  }
}

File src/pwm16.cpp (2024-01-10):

#include "pwm16.h"

uint16_t pwmDC = 0;

void setupPWM16(uint8_t bits)
{
    uint16_t icr = 0xffff;
    pwmDC = pow(2, bits) - 1;
    OCR1A = 0;
    OCR1B = 0;
    switch (bits)
    {
    case 16:
        icr = 0xffff;
        break;
    case 15:
        icr = 0x7fff;
        break;
    case 14:
        icr = 0x3fff;
        break;
    case 13:
        icr = 0x1fff;
        break;
    case 12:
        icr = 0x0fff;
        break;
    case 11:
        icr = 0x07ff;
        break;
    case 10:
        icr = 0x03ff;
        break;
    case 9:
        icr = 0x01ff;
        break;
    case 8:
        icr = 0x00ff;
        break;
    default:
        icr = 0x00ff;
        break;
    }
    DDRB |= _BV(PB1) | _BV(PB2);                  /* set pins as outputs */
    TCCR1A = _BV(COM1A1) | _BV(COM1B1)            /* non-inverting PWM */
             | _BV(WGM11);                        /* mode 14: fast PWM, TOP=ICR1 */
    TCCR1B = _BV(WGM13) | _BV(WGM12) | _BV(CS10); /* prescaler 1 */
    ICR1 = icr;                                   /* TOP counter value (freeing OCR1A*/
    // Serial.print("ICR1:");
    // Serial.println(icr);
}

/* 16-bit version of analogWrite(). Works only on pins 9 and 10. */
void analogWrite16(uint8_t pin, uint16_t val)
{
    switch (pin)
    {
    case 9:
        if (val <= 0)
            digitalWrite(9, LOW);
        if ((val > 0) & (val < pwmDC))
            OCR1A = val;
        if (val >= pwmDC)
            digitalWrite(9, LOW);
        break;
    case 10:
        if (val <= 0)
            digitalWrite(10, LOW);
        if ((val > 0) & (val < pwmDC))
            OCR1B = val;
        if (val >= pwmDC)
            digitalWrite(10, LOW);
        break;
    }
}

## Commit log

2023-10-19 adicionado opcao de mudar valor de input
2023-10-28 adicionado lógica para encoder interar com LCD
2023-11-03 update encoder functions for LCD
2023-11-16 adicionado biblioteca para logs
2023-11-16 adicionado interrupção para o sensor
2023-11-16 atualizado função de interrupção
2023-11-17 adicionado biblioteca de pwm de 16bits
2023-11-17 adicionado rotina de pwm
2023-11-18 adicionado função de saida analogica
2023-11-18 adicionado funções de recuperacao de dados na memoria
2023-11-21 atualizado rotina de interrupção e carregamento de configurações
2023-11-22 README atualizado incluindo pinout do Arduino Nano
2023-11-22 atualizado funcao de interrupcao e conversao de tempo para tensao
2023-12-06 update interrupt
2023-12-06 update test function and pin interrupt
2023-12-13 update encoder routine for ISR
2023-12-26 adicionado adc para leitura do DAC
2024-01-10 new document
    [Lista de Material.xlsx]
2024-01-10 new 3D Models
    [16Bit I2C ADC+PGA - ADS1115.stp, 2.54 5PIN 90.SLDPRT, Adafruit MCP4725.step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]
